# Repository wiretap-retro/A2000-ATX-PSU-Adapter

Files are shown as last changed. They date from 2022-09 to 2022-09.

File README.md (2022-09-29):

# A2000 ATX PSU Adapter
A power supply adapter for the Amiga 2000 to use an ATX power supply -- also provides -5VDC, 5V & 12V fan headers.

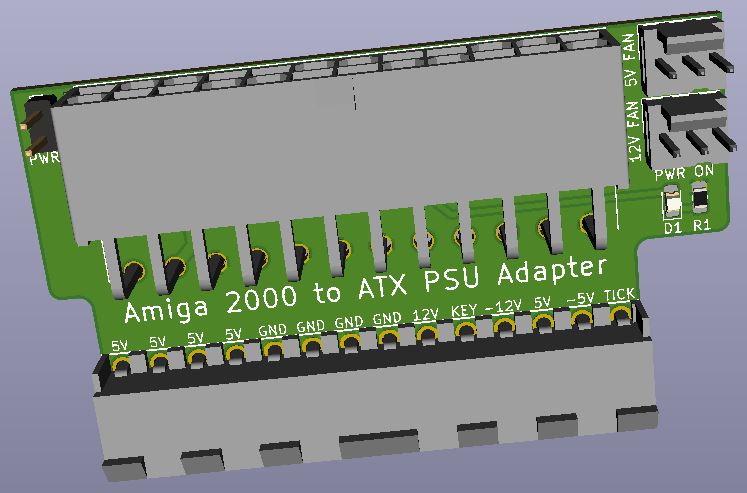
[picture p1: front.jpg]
front

\
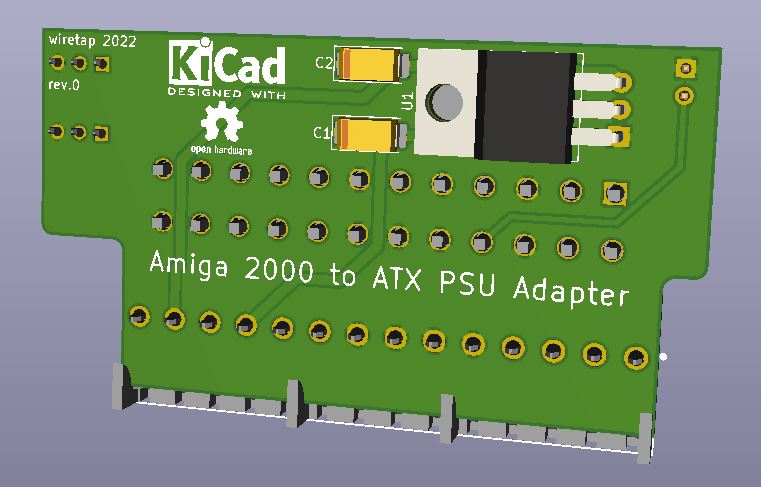
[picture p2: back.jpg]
back


## Assembly
* Order the board from your PCB fabricator of choice. (JLCPCB, PCBway, OSH Park, etc.)
* Order the parts per the BOM. (Mouser, Digikey, RS, etc.)
* Solder the D1 and R1 first. (optional, for ATX "power good" signal indication)
* Solder C1 and C2 capacitors.
* Install U1 through the board, bend over the leads, flush clip them, then solder.
* Solder J1, then J2.
* Solder the power switch pin header and the fan headers.

## Installation
* Install an ATX power supply in your Amiga 2000. This step is not covered here, as there are many tutorials online already. Do not cut the 20-pin/24-pin connector.
* Set motherboard jumper U300 for using the Vsync generated TICK signal.
* Plug the A2000 ATX PSU Adapter into the motherboard's power connector.
* Plug in a toggle switch or latching switch to the 2-pin PWRSW pin header. The button can be mounted anywhere you run the wires to, or you can also use the original power supply's rocker switch to keep the OEM look and feel. You can also install a jumper here, if you want to utilize your ATX/SFX power supply rocker switch in the case of just plopping the power supply on the desk or modding the case to mount the whole thing in there.
* Connect your ATX power supply 20-pin/24-pin connector to your newly built power adapter.
* Optional: The board provides 5V and 12V fan headers to cool anything you want. For example, the 5V fan header is good for a Raspberry Pi fan for the PiSTORM.

## Notes
* The 7905 voltage regulator takes power from the -12VDC ATX power supply and converts it to -5VDC for the Amiga. It is capable of providing plenty of power, and is overkill. Your ATX power supply -12VDC rail will tap out well before the abilities of the 7905.
* This ATX power supply adapter will probably be a little difficult to remove since it is a 14-pin connector with high friction. Be careful if you remove it. I designed it with the edges protruding a little so you have something to grip. Insertion/removal may be easier if the ATX power supply is already connected since you'll have additional plastic to grab onto. A slight rocking motion will help get the connector over the bump.
* This is a 4-layer board with the inner planes being 5V and 12V. I increased the width of the thermal reliefs to allow sufficient current to pass, so soldering will be a little more difficult due to heat transfer to the large planes. Use a larger tip and a higher temperature when soldering to make sure the fillets look nice and no dry solder joints occur.

## Revision Info
* Rev 1: Changed power indication LED from the PG pin to a 5V source. The PG pin only stays high for about 5 seconds depending on the power supply.
* Rev 0: Initial revision.

## Misc
* This design is open source. Feel free to do what you want with it.
* Design adapted from my PICO-AT power adapter.

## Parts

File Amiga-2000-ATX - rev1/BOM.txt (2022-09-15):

U1 - 7905 Voltage Regulator -- L7905CV
C1 - 2.2uF 2312 Tantalum Capacitor -- T491C225K035AT
C2 - 1uF 2312 Tantalum Capacitor -- T491C105K050AT
D1 - 0805 size LED of your choice
R1 - 0805 size resistor for corresponding LED forward voltage (5VDC goes to LED)
J1 - 14-pin KK396 board-to-wire 90-deg connector -- Molex 09-48-1164
J2 - 24-pin ATX board to wire 90-deg connector -- Molex 87427-2402
J3 - 3-pin vertical fan header -- Molex 22-23-2031
J4 - 3-pin vertical fan header -- Molex 22-23-2031
J5 - 2-pin 2.54mm pitch vertical pin header

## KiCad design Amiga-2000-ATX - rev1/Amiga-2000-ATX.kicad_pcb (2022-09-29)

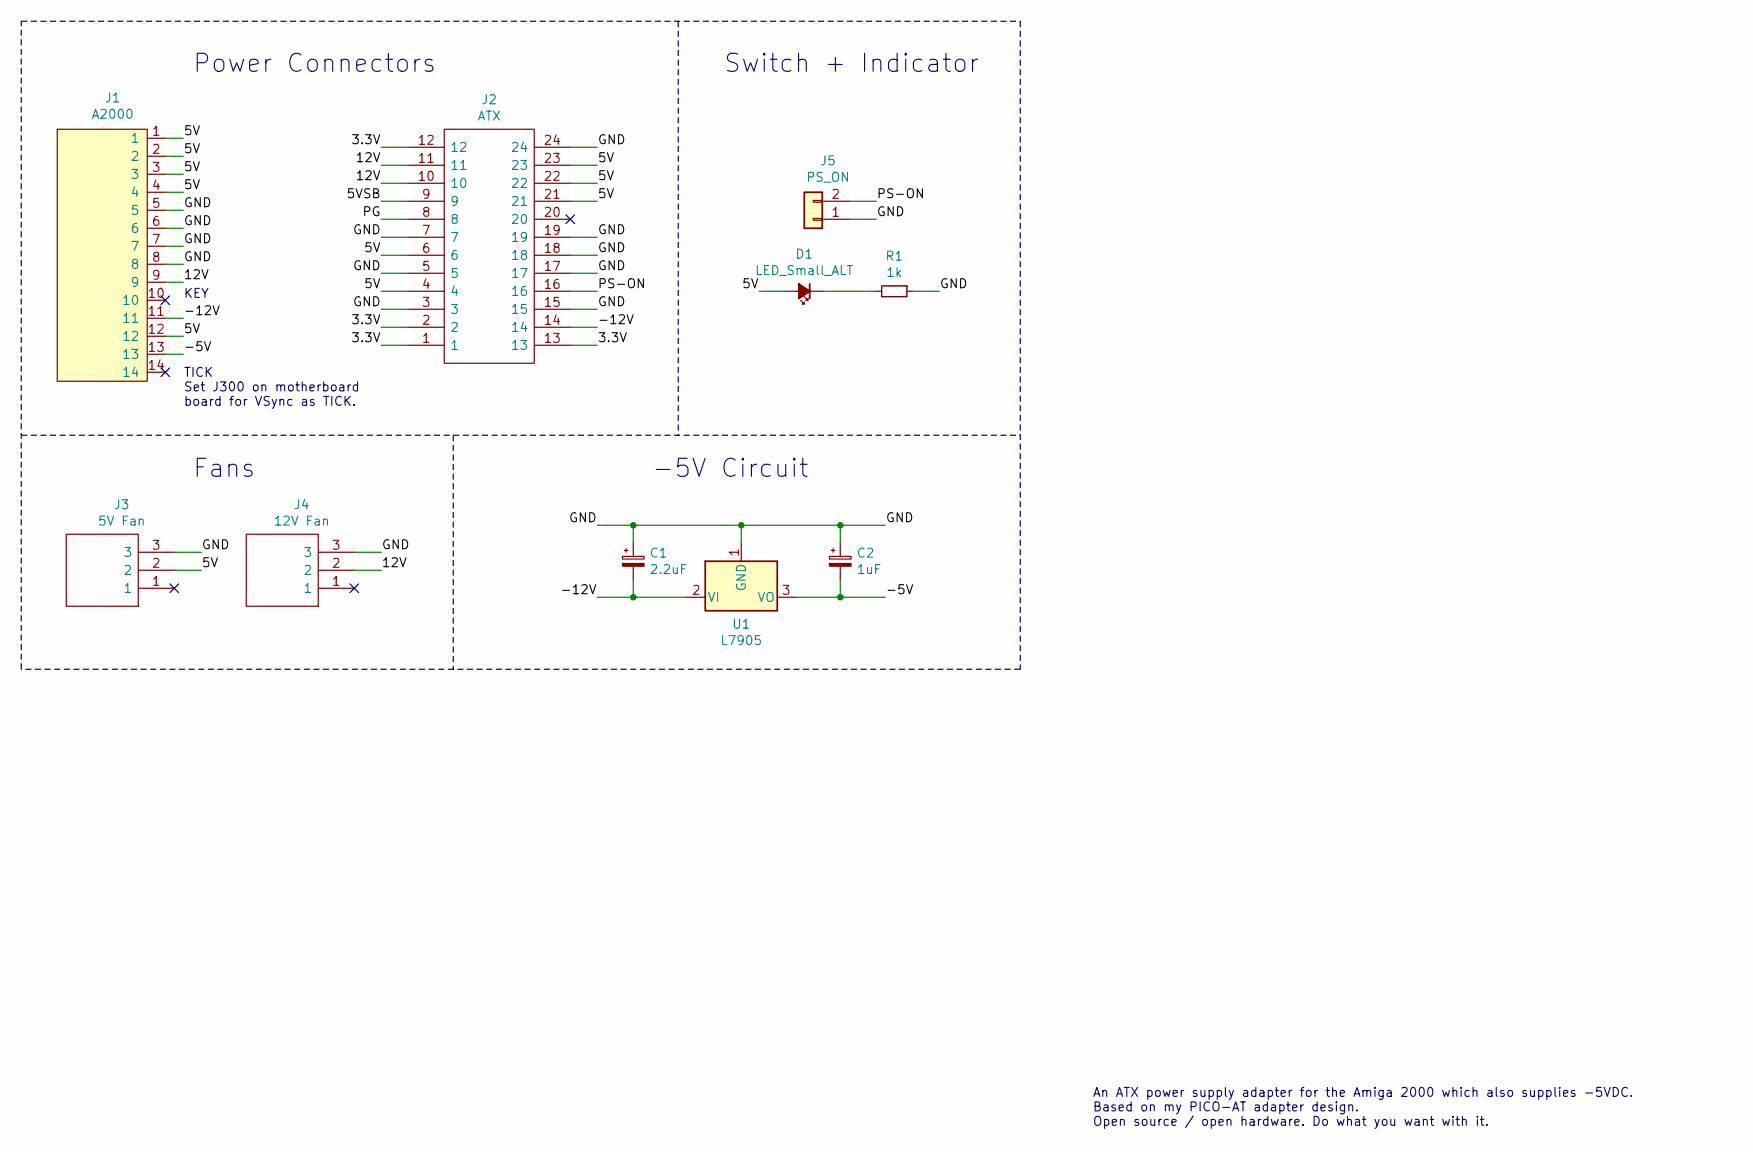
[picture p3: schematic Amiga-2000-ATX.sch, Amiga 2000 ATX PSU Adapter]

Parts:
C1: 2.2uF; CP_EIA-6032-28_Kemet-C_Pad2.25x2.35mm_HandSolder
C2: 1uF; CP_EIA-6032-28_Kemet-C_Pad2.25x2.35mm_HandSolder
D1: LED_Small_ALT; LED_0805_2012Metric_Castellated
J1: A2000; 09481164
J2: ATX; 87427-2402; Mouser Part Number 538-87427-2402
J3: 5V Fan; SHDR3W82P0X254_1X3_747X635X818P; Mouser Part Number 538-22-23-2031
J4: 12V Fan; SHDR3W82P0X254_1X3_747X635X818P; Mouser Part Number 538-22-23-2031
J5: PS_ON; PinHeader_1x02_P2.54mm_Vertical
R1: 1k; R_0805_2012Metric_Pad1.15x1.40mm_HandSolder
U1: L7905; TO-220-3_Horizontal_TabDown

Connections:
/3.3V: J2.1, J2.2, J2.12, J2.13
/5V: D1.2 (A), J1.1, J1.2, J1.3, J1.4, J1.12, J2.4, J2.6, J2.21, J2.22, J2.23, J3.2
/5VSB: J2.9
/12V: J1.9, J2.10, J2.11, J4.2
/-5V: C2.2, J1.13, U1.3 (VO)
/-12V: C1.2, J1.11, J2.14, U1.2 (VI)
/GND: C1.1, C2.1, J1.5, J1.6, J1.7, J1.8, J2.3, J2.5, J2.7, J2.15, J2.17, J2.18, J2.19, J2.24, J3.3, J4.3, J5.1, R1.1, U1.1 (GND); also elsewhere on the board
/PG: J2.8
/PS-ON: J2.16, J5.2; also elsewhere on the board
unnamed: D1.1 (K), R1.2

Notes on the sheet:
TICK Set J300 on motherboard board for VSync as TICK.
KEY
Fans
Switch + Indicator
-5V Circuit
Power Connectors
An ATX power supply adapter for the Amiga 2000 which also supplies -5VDC. Based on my PICO-AT adapter design. Open source / open hardware. Do what you want with it.

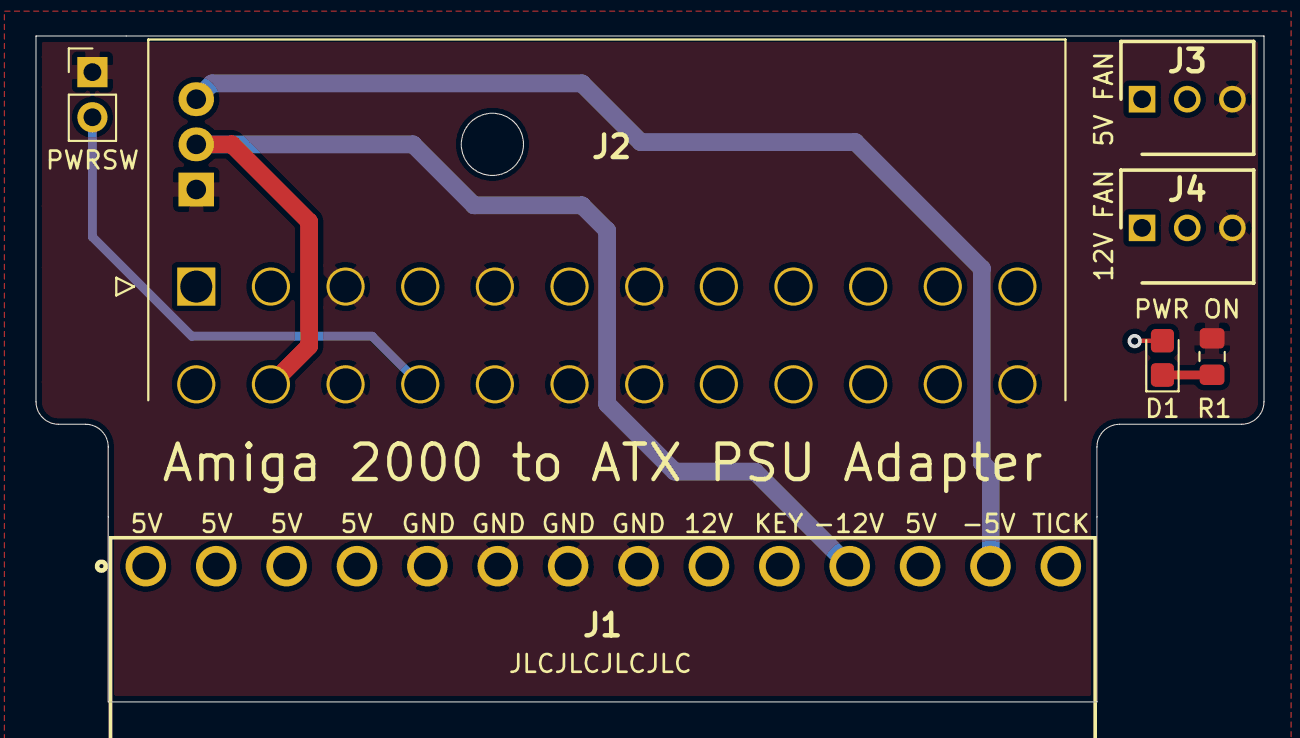
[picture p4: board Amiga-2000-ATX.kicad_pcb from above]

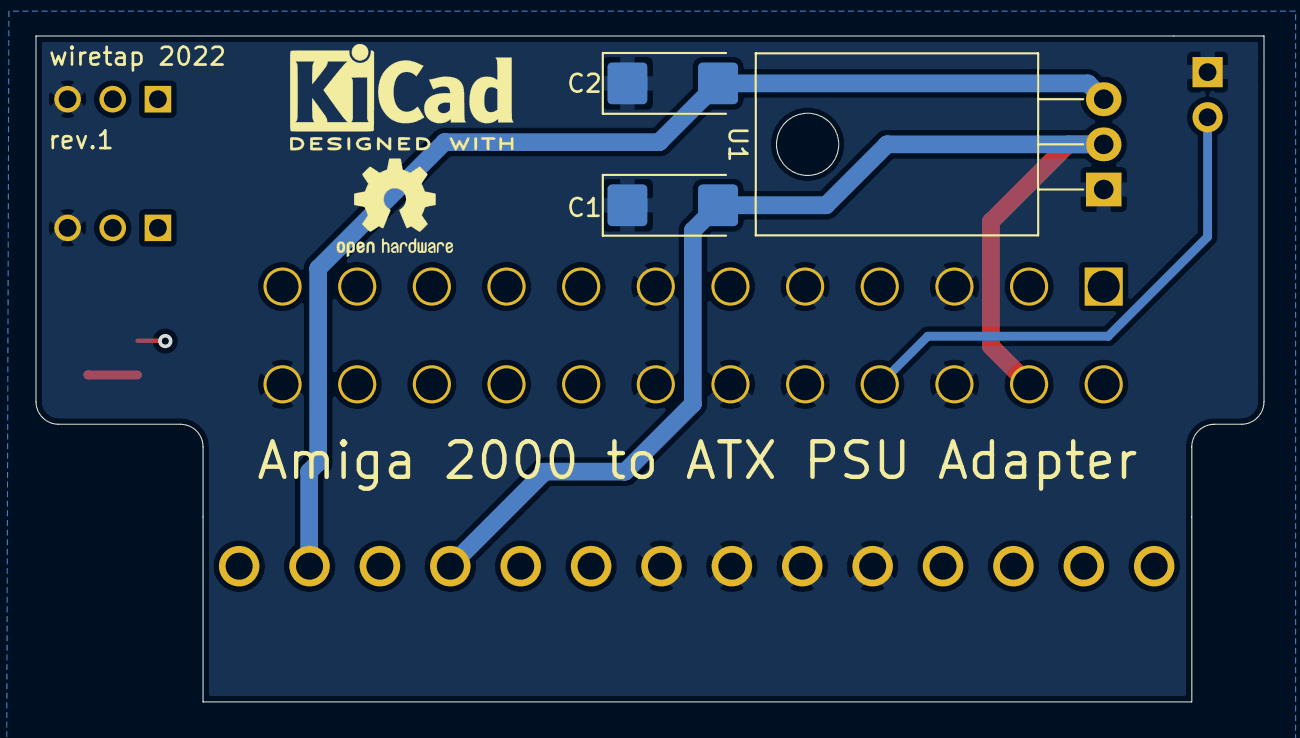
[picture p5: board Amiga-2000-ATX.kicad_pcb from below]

Board: 4 copper layers, 69.1 x 37.5 mm, 10 parts (3 on the bottom side), 8 nets.

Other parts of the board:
PWRSW: PS_ON; PinHeader_1x02_P2.54mm_Vertical

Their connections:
/GND: PWRSW.1; also elsewhere on the board
/PS-ON: PWRSW.2; also elsewhere on the board
